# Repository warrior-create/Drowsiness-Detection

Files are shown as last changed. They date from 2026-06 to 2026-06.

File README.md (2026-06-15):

# 🚗 SafeDash — Real-Time Driver Drowsiness Detection & Monitoring System

> An embedded AI system for real-time driver attention monitoring, built on NVIDIA Jetson Nano.  
> Developed at the **School of Computing and Electrical Engineering, IIT Mandi**.

📄 [Project Report](https://drive.google.com/drive/folders/1U4jq64dsoF5--_NPGIv1SxsrH9lrvMU_) · 🎥 [Demo Videos](https://drive.google.com/drive/folders/1U4jq64dsoF5--_NPGIv1SxsrH9lrvMU_) · 🔩 [CAD Files](https://github.com/SHRI-14/SAFEDASH/tree/main/CAD)

---

## Overview

SafeDash is a low-cost, non-invasive driver monitoring system that detects drowsiness and inattention in real time using a standard USB webcam and the MediaPipe face tracking pipeline running on an NVIDIA Jetson Nano. When unsafe behaviour is detected, a three-stage alert mechanism (visual → audio → haptic) progressively re-engages the driver. All data is streamed to a Flask + Redis web dashboard for live and historical analysis.

---

## Features

- **Real-time facial landmark tracking** — MediaPipe Face Mesh extracts 468 landmarks per frame at 30+ FPS on-device
- **Unified Attention Score (1–5)** — computed from eye closure (EAR), yawning (MAR), blink rate, and head pose
- **Three-stage alert system**
  - 🖥️ Stage 1 — Visual warning on integrated LCD
  - 🔊 Stage 2 — Voice alert via external speaker
  - 📳 Stage 3 — Haptic feedback via steering-mounted vibration motors
- **Web dashboard** — live attention score, blink rate, head orientation (yaw/pitch/roll), eye state, and historical charts
- **Automatic email alerts** — SMTP notification to supervisors when attention drops below threshold (15-second cooldown)
- **Redis time-series storage** — data auto-expires after 24 hours; supports multi-device fleet monitoring
- **Face-not-detected logic** — triggers haptic + audio alert if face is absent for >4 seconds
- **Custom acrylic enclosure** — SolidWorks-designed, laser-cut black acrylic housing with thermal management

---

## System Architecture

```
USB Webcam
    │
    ▼
MediaPipe Face Mesh (468 landmarks)
    │
    ├── Eye Aspect Ratio (EAR)   →  Eye closure / blink detection
    ├── Mouth Aspect Ratio (MAR) →  Yawn detection
    ├── Blink Rate (BR)          →  Sliding 5s window
    └── Head Pose (Yaw/Pitch/Roll)
    │
    ▼
Unified Attention Score (1–5)
    │
    ├── Alert Engine  →  LCD / Speaker / Haptic Motors
    └── Flask Backend →  Redis →  Web Dashboard + Email Alerts
```

---

## Hardware

| Component | Details |
|---|---|
| Processor | NVIDIA Jetson Nano 4GB |
| Camera | USB Webcam (RGB, 30–45 FPS) |
| Display | 3.2-inch HDMI LCD |
| Audio | External speaker via USB sound card |
| Haptic | 2× DC vibration motors (steering-mounted) via L298N driver |
| Connectivity | Intel AC8265 Wi-Fi module |
| Storage | 32 GB micro-SD |
| Power | 12V (actuators) / 5V (Jetson & logic) via automotive buck converters |
| Enclosure | 3mm black acrylic, laser-cut, SolidWorks design |

**Total BOM cost: ~₹12,000**

---

## Software Stack

- **Edge (Jetson):** Python, MediaPipe, OpenCV, Haarcascade (fallback detector)
- **Backend:** Flask, Redis
- **Frontend:** Chart.js (real-time graphs), HTML/CSS dashboard
- **Alerts:** SMTP email

---

## Repository Structure

```
SAFEDASH/
├── model.py                          # Attention scoring & drowsiness detection logic
├── stream_server.py                  # Flask backend + Redis + dashboard server
├── haarcascade_eye.py                # Haarcascade eye detector (fallback)
├── haarcascade_frontalface_default.py # Haarcascade face detector (fallback)
├── test_driver.py                    # Testing / simulation script
└── CAD/                              # SolidWorks enclosure design files
```

---

## Getting Started

### Prerequisites

- NVIDIA Jetson Nano with JetPack installed (or any Linux machine for testing)
- Python 3.8+
- Redis server
- USB webcam

### Installation

```bash
# Clone the repository
git clone https://github.com/SHRI-14/SAFEDASH.git
cd SAFEDASH

# Create and activate virtual environment
python3 -m venv venv
source venv/bin/activate

# Install dependencies
pip install flask mediapipe opencv-python redis numpy
```

### Running

```bash
# Start Redis (in a separate terminal)
redis-server

# Start the stream server / dashboard
python3 stream_server.py
```

The dashboard will be available at **http://localhost:5001**

To run the drowsiness detection model on the Jetson:

```bash
python3 model.py
```

---

## Attention Scoring Algorithm

The system computes a normalized attention rating on a **1–5 scale**:

| Feature | Weight | Condition |
|---|---|---|
| Eye state (EAR) | 4 | Open = 1, Closed = 0 (threshold: EAR < 0.26) |
| Mouth state (MAR) | 2 | Closed = 1, Yawning = 0 (threshold: MAR > 0.40) |
| Head/Neck pose | 3 | 0–2 based on yaw/roll angles |
| Blink rate | 3 | Normal (1–3 blinks/s) = 1, else 0 |

**Raw score max = 15 → Normalized to 1–5 range**

Alert threshold: Score < 2

---

## Dashboard

The web dashboard supports:
- Live attention score with color-coded risk severity
- Real-time charts: attention score, blink frequency, head orientation (yaw/pitch/roll)
- Aggregated bar charts (1–60 min time ranges)
- Multi-device fleet monitoring via unique Jetson IDs
- Data refresh every 5 seconds

---

**School of Computing and Electrical Engineering, IIT Mandi**

**Advisors:** Dr. Rohit Saluja, Dr. Gajendra Singh

---

## Acknowledgements

Thanks to the School of Computing and Electrical Engineering at IIT Mandi for providing laboratory facilities, equipment, and technical guidance throughout the project.

---

## License

This project was developed for academic purposes at IIT Mandi. Please contact the authors for usage permissions.

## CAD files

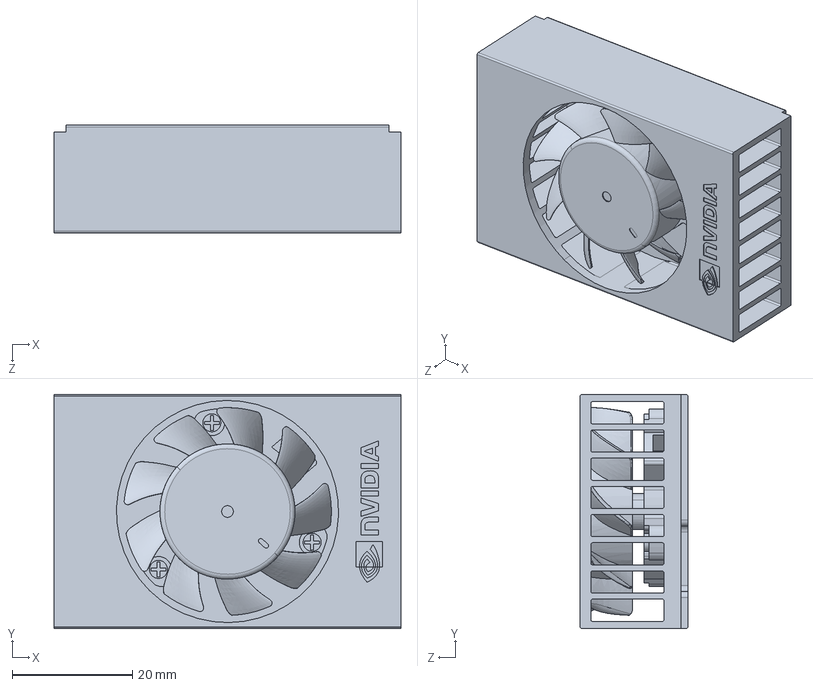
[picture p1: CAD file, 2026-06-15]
CAD/Xavier_NX_FANSINK_P3518_ASM[1].SLDPRT
57.8 x 39.0 x 18.0 mm

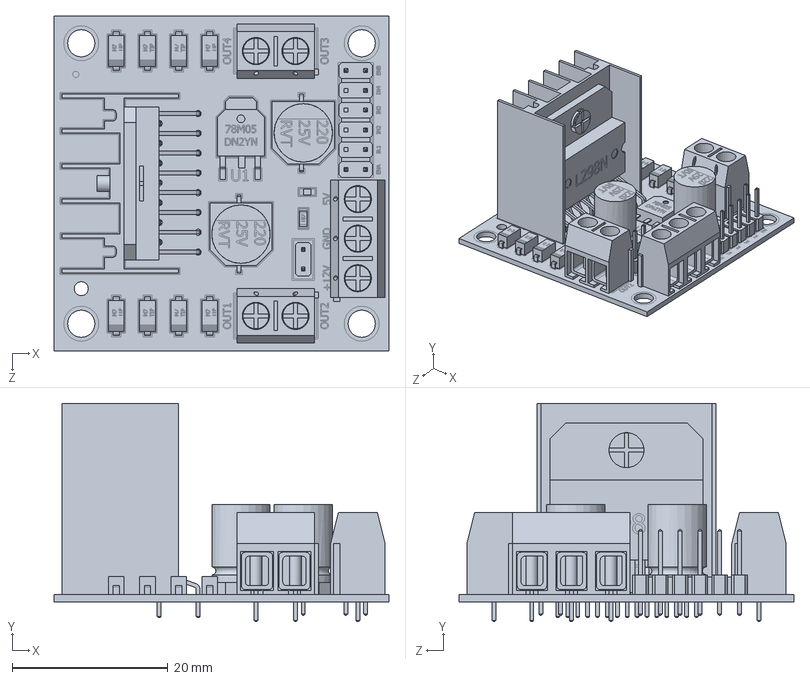
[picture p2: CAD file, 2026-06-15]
CAD/L298N.SLDPRT
43.0 x 28.0 x 43.0 mm

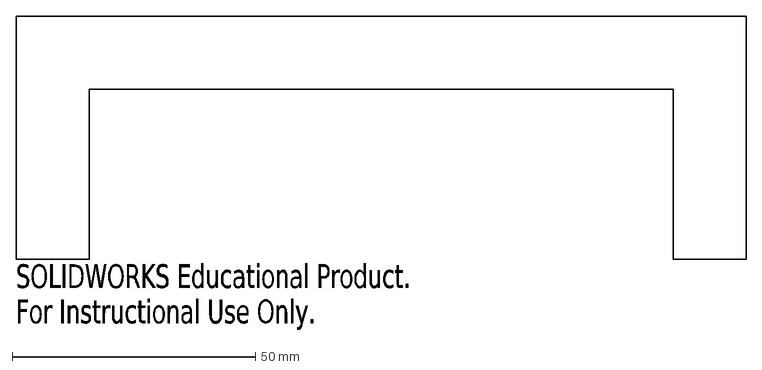
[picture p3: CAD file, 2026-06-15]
CAD/back.DXF
SOLIDWORKS Educational Product.
For Instructional Use Only.

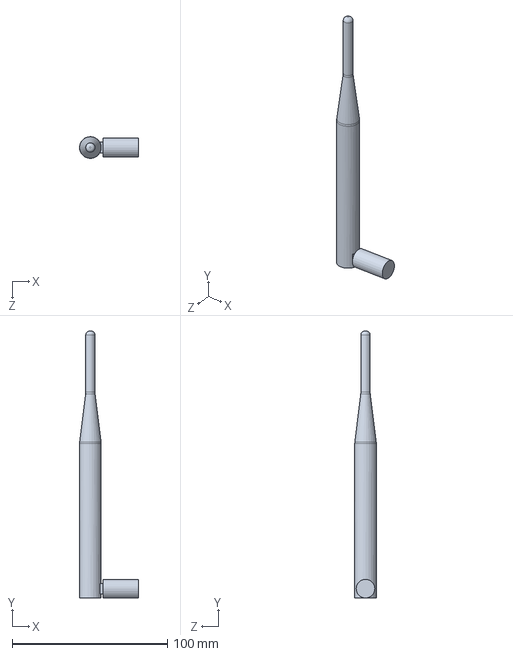
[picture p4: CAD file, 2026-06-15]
CAD/Antenna90deg[1].SLDPRT
38.0 x 172.0 x 14.0 mm

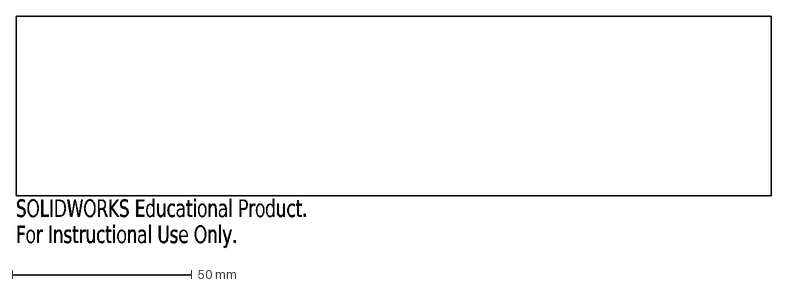
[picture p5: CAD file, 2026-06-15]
CAD/side.DXF
SOLIDWORKS Educational Product.
For Instructional Use Only.

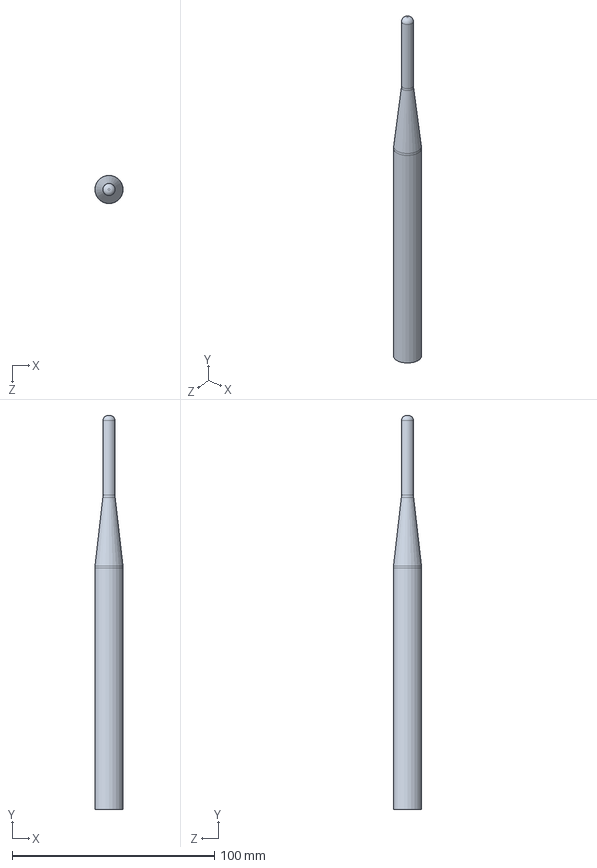
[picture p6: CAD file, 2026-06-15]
CAD/Antenna[1].SLDPRT
14.0 x 195.0 x 14.0 mm

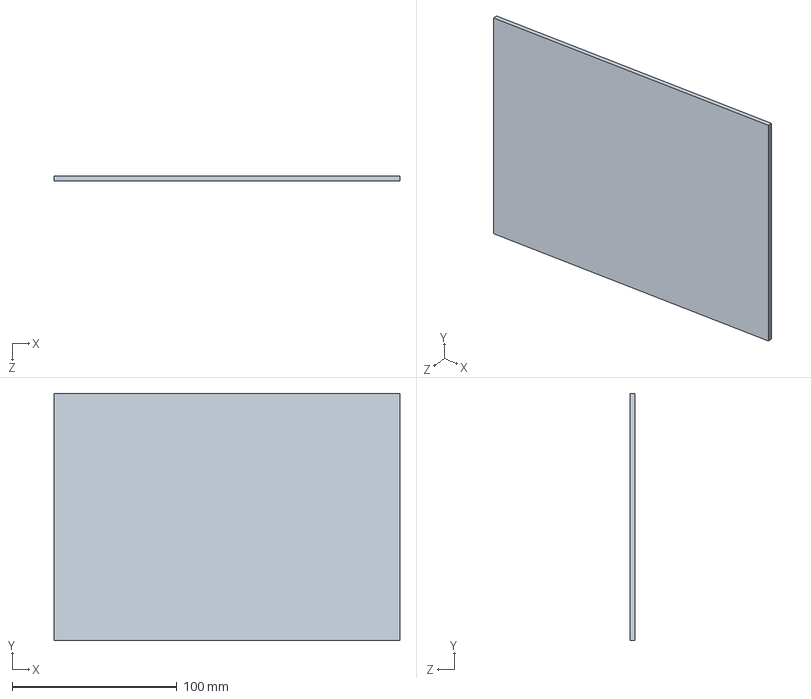
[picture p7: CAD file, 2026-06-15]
CAD/Part209.SLDPRT
210.0 x 150.0 x 3.00 mm

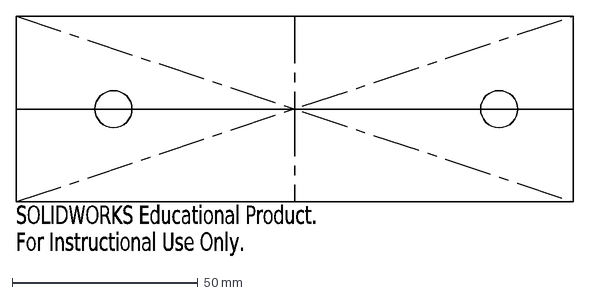
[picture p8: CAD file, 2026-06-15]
CAD/front.DXF
SOLIDWORKS Educational Product.
For Instructional Use Only.

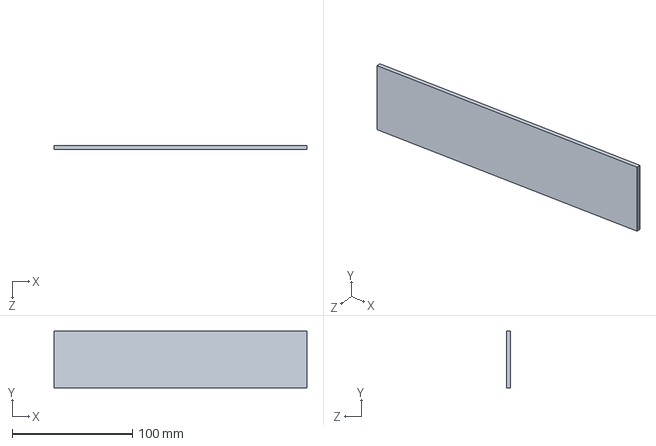
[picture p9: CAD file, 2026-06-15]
CAD/Part210.SLDPRT
210.0 x 47.0 x 3.00 mm

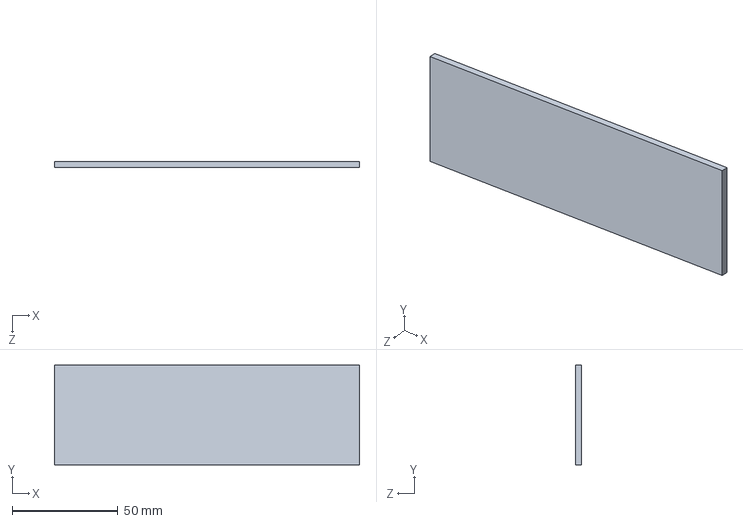
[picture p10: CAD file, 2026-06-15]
CAD/Part1.SLDPRT
144.0 x 47.0 x 3.00 mm

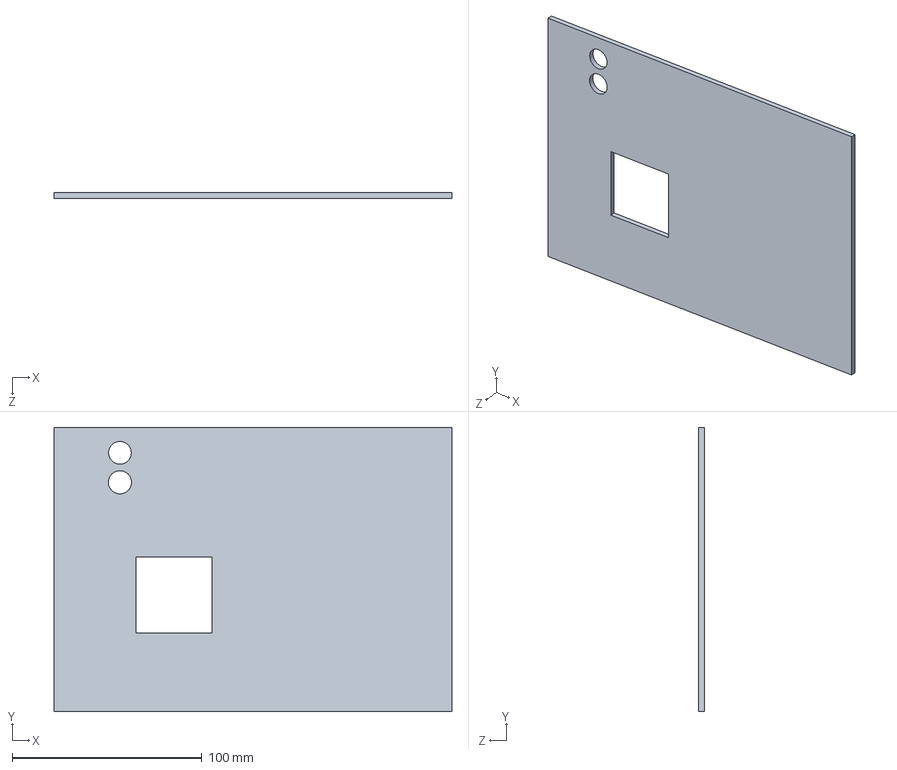
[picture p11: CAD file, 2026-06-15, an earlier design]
CAD/Part209 - Copy.SLDPRT
210.0 x 150.0 x 3.00 mm

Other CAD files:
CAD/top.SLDPRT
CAD/top2.SLDPRT
CAD/Part1 - Copy.SLDPRT
CAD/top.DXF
CAD/top.SLDDRW
CAD/top2.DXF

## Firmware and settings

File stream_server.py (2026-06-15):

from flask import Flask, request, jsonify, render_template_string
import redis
import json
from datetime import datetime, timedelta
import smtplib
from email.mime.text import MIMEText
from email.mime.multipart import MIMEMultipart
from threading import Thread, Lock
import time
from collections import Counter

app = Flask(__name__)

REDIS_HOST = 'localhost'
REDIS_PORT = 6379
REDIS_DB = 0
DATA_RETENTION_HOURS = 24

SMTP_SERVER = "smtp.gmail.com"
SMTP_PORT = 587

SENDER_EMAIL = "b24225@students.iitmandi.ac.in"
SENDER_PASSWORD = "vamcwrsjpsfjlzhq"
RECIPIENT_EMAIL = "b24160@students.iitmandi.ac.in"

ALERT_THRESHOLD = 2
ALERT_COOLDOWN = 15

redis_client = redis.Redis(
    host=REDIS_HOST,

    port=REDIS_PORT,
    db=REDIS_DB,
    decode_responses=True
)

alert_state = {}
alert_lock = Lock()

def store_data_in_redis(data):
    try:
        jetson_id = data.get('jetson_id', 'unknown')
        epoch_time = data.get('epoch_time', time.time())
        key = f"data:{jetson_id}:{epoch_time}"
        redis_client.setex(key, timedelta(hours=DATA_RETENTION_HOURS), json.dumps(data))
        redis_client.zadd(f"timeline:{jetson_id}", {key: epoch_time})
        redis_client.expire(f"timeline:{jetson_id}", timedelta(hours=DATA_RETENTION_HOURS))
        return True
    except Exception as e:
        print(f"Redis storage error: {e}")
        return False

def get_recent_data(jetson_id, hours=1):
    try:
        current_time = time.time()
        start_time = current_time - (hours * 3600)
        keys = redis_client.zrangebyscore(f"timeline:{jetson_id}", start_time, current_time)
        data_list = []
        for key in keys:
            data_str = redis_client.get(key)
            if data_str:
                data_list.append(json.loads(data_str))
        data_list.sort(key=lambda x: x.get('epoch_time', 0))
        return data_list
    except Exception as e:
        print(f"Redis retrieval error: {e}")
        return []

def send_alert_email(jetson_id, attention_score, data):
    try:
        # --- 1. Extract Location Data ---
        lat = data.get('latitude', 'N/A')
        lon = data.get('longitude', 'N/A')

        # --- 2. Generate Maps Link ---
        maps_section = ""
        if lat != 'N/A' and lon != 'N/A':
            maps_link = f"https://www.google.com/maps?q={lat},{lon}"
            maps_section = f"""
            <div style="margin-top: 20px; border-top: 1px solid #eee; padding-top: 15px;">
                <a href="{maps_link}" style="background-color: #1e40af; color: white; padding: 12px 20px; text-decoration: none; border-radius: 6px; font-weight: bold; display: inline-block;">
                    📍 View Location on Google Maps
                </a>
            </div>
            """

        subject = f"CRITICAL: Driver Attention Alert - {jetson_id}"
        
        # --- 3. Updated HTML Body ---
        body = f"""
        <html>
        <body style="font-family: 'Segoe UI', Arial, sans-serif; background-color: #f1f5f9; padding: 20px;">
            <div style="max-width: 600px; margin: 0 auto; background: white; border-radius: 12px; overflow: hidden; box-shadow: 0 4px 6px -1px rgba(0, 0, 0, 0.1);">
                
                <div style="background: #dc2626; color: white; padding: 24px; text-align: center;">
                    <h2 style="margin: 0; font-size: 24px; letter-spacing: 1px;">DRIVER SAFETY ALERT</h2>
                    <p style="margin: 5px 0 0 0; opacity: 0.9;">Immediate Attention Required</p>
                </div>

                <div style="padding: 30px;">
                    
                    <div style="text-align: center; margin-bottom: 25px; background: #fef2f2; padding: 15px; border-radius: 8px; border: 1px solid #fecaca;">
                        <p style="margin: 0; color: #7f1d1d; font-size: 14px; text-transform: uppercase; font-weight: bold;">Attention Score</p>
                        <div style="font-size: 36px; font-weight: 800; color: #dc2626; margin: 5px 0;">{attention_score}/5</div>
                        <div style="color: #991b1b; font-weight: 600;">{data.get('attention_label', 'N/A')}</div>
                    </div>

                    <table style="width: 100%; border-collapse: collapse; margin-bottom: 20px;">
                        <tr>
                            <td style="padding: 10px; border-bottom: 1px solid #e2e8f0; color: #64748b;">Vehicle ID</td>
                            <td style="padding: 10px; border-bottom: 1px solid #e2e8f0; font-weight: 600; color: #0f172a;">{jetson_id}</td>
                        </tr>
                        <tr>
                            <td style="padding: 10px; border-bottom: 1px solid #e2e8f0; color: #64748b;">Time</td>
                            <td style="padding: 10px; border-bottom: 1px solid #e2e8f0; font-weight: 600; color: #0f172a;">{data.get('timestamp', 'N/A')}</td>
                        </tr>
                        <tr>
                            <td style="padding: 10px; border-bottom: 1px solid #e2e8f0; color: #64748b;">Eye Status</td>
                            <td style="padding: 10px; border-bottom: 1px solid #e2e8f0; font-weight: 600; color: #0f172a;">{data.get('eye_status', 'N/A')}</td>
                        </tr>
                        <tr>
                            <td style="padding: 10px; border-bottom: 1px solid #e2e8f0; color: #64748b;">Drowsiness</td>
                            <td style="padding: 10px; border-bottom: 1px solid #e2e8f0; font-weight: 700; color: {'#dc2626' if data.get('is_drowsy', False) else '#16a34a'};">
                                {'DETECTED' if data.get('is_drowsy', False) else 'None'}
                            </td>
                        </tr>
                        <tr>
                            <td style="padding: 10px; border-bottom: 1px solid #e2e8f0; color: #64748b;">GPS Coordinates</td>
                            <td style="padding: 10px; border-bottom: 1px solid #e2e8f0; font-family: monospace; color: #0f172a;">
                                {lat}, {lon}
                            </td>
                        </tr>
                    </table>

                    {maps_section}

                </div>

                <div style="background: #f8fafc; padding: 15px; text-align: center; border-top: 1px solid #e2e8f0;">
                    <p style="margin: 0; font-size: 12px; color: #94a3b8;">
                        Sent automatically by Driver Safety Monitoring System<br>
                        Logged at: {datetime.now().strftime('%Y-%m-%d %H:%M:%S')}
                    </p>
                </div>
            </div>
        </body>
        </html>
        """
        
        msg = MIMEMultipart('alternative')
        msg['Subject'] = subject
        msg['From'] = SENDER_EMAIL
        msg['To'] = RECIPIENT_EMAIL
        html_part = MIMEText(body, 'html')
        msg.attach(html_part)
        
        server = smtplib.SMTP(SMTP_SERVER, SMTP_PORT)
        server.starttls()
        server.login(SENDER_EMAIL, SENDER_PASSWORD)
        server.send_message(msg)
        server.quit()
        return True
    except Exception as e:
        print(f"Email error: {e}")
        return False

def check_and_send_alert(data):
    jetson_id = data.get('jetson_id', 'unknown')
    attention_score = data.get('attention_score', 5)
    if attention_score < ALERT_THRESHOLD:
        with alert_lock:
            current_time = time.time()
            last_alert_time = alert_state.get(jetson_id, 0)
            if current_time - last_alert_time >= ALERT_COOLDOWN:
                Thread(target=send_alert_email, args=(jetson_id, attention_score, data), daemon=True).start()
                alert_state[jetson_id] = current_time

@app.route('/stream', methods=['POST'])
def receive_stream():
    try:
        data = request.get_json()
        if not data:
            return jsonify({"error": "No data received"}), 400
        if store_data_in_redis(data):
            check_and_send_alert(data)
            return jsonify({
                "status": "success",
                "message": "Data received and stored",
                "jetson_id": data.get('jetson_id'),
                "timestamp": data.get('timestamp')
            }), 200
        else:
            return jsonify({"error": "Failed to store data"}), 500
    except Exception as e:
        print(f"Error processing stream: {e}")
        return jsonify({"error": str(e)}), 500

@app.route('/api/data/<jetson_id>')
def get_data_api(jetson_id):
    hours = request.args.get('hours', default=1, type=int)
    data = get_recent_data(jetson_id, hours)
    return jsonify(data)

@app.route('/api/devices')
def get_devices():
    try:
        keys = redis_client.keys("timeline:*")
        devices = [key.replace("timeline:", "") for key in keys]
        return jsonify({"devices": devices})
    except Exception as e:
        return jsonify({"error": str(e)}), 500

@app.route('/')
def dashboard():
    return render_template_string(DASHBOARD_HTML)

@app.route('/dashboard/<jetson_id>')
def device_dashboard(jetson_id):
    return render_template_string(DEVICE_DASHBOARD_HTML, jetson_id=jetson_id)

DASHBOARD_HTML = '''
<!DOCTYPE html>
<html lang="en">
<head>
    <meta charset="UTF-8">
    <meta name="viewport" content="width=device-width, initial-scale=1.0">
    <title>Driver Safety Monitoring System</title>
    <script src="https://cdn.tailwindcss.com"></script>
    <script>
        tailwind.config = {
            theme: {
                extend: {
                    colors: {
                        primary: '#1e40af',
                        secondary: '#64748b',
                    }
                }
            }
        }
    </script>
</head>
<body class="bg-slate-50">
    <nav class="bg-white border-b border-slate-200">
        <div class="max-w-7xl mx-auto px-6 py-4">
            <div class="flex items-center justify-between">
                <div class="flex items-center space-x-4">
                    <div class="w-12 h-12 bg-blue-600 rounded-lg flex items-center justify-center">
                        <svg class="w-6 h-6 text-white" fill="none" stroke="currentColor" viewBox="0 0 24 24">
                            <path stroke-linecap="round" stroke-linejoin="round" stroke-width="2" d="M9 12l2 2 4-4m5.618-4.016A11.955 11.955 0 0112 2.944a11.955 11.955 0 01-8.618 3.04A12.02 12.02 0 003 9c0 5.591 3.824 10.29 9 11.622 5.176-1.332 9-6.03 9-11.622 0-1.042-.133-2.052-.382-3.016z"></path>
                        </svg>
                    </div>
                    <div>
                        <h1 class="text-xl font-bold text-slate-900">Driver Safety Monitor</h1>
                        <p class="text-sm text-slate-600">Real-time Fleet Management</p>
                    </div>
                </div>
                <div class="flex items-center space-x-2 px-4 py-2 bg-green-50 border border-green-200 rounded-lg">
                    <div class="w-2 h-2 bg-green-500 rounded-full animate-pulse"></div>
                    <span class="text-sm font-semibold text-green-700">System Active</span>
                </div>
            </div>
        </div>
    </nav>

    <main class="max-w-7xl mx-auto px-6 py-8">
        <div class="grid grid-cols-1 lg:grid-cols-3 gap-6 mb-8">
            <div class="bg-gradient-to-br from-blue-50 to-blue-100 rounded-xl p-6 border border-blue-200">
                <div class="w-16 h-16 bg-blue-600 rounded-xl flex items-center justify-center mb-4">
                    <svg class="w-10 h-10 text-white" fill="none" stroke="currentColor" viewBox="0 0 24 24">
                        <path stroke-linecap="round" stroke-linejoin="round" stroke-width="2" d="M15 12a3 3 0 11-6 0 3 3 0 016 0z"></path>
                        <path stroke-linecap="round" stroke-linejoin="round" stroke-width="2" d="M2.458 12C3.732 7.943 7.523 5 12 5c4.478 0 8.268 2.943 9.542 7-1.274 4.057-5.064 7-9.542 7-4.477 0-8.268-2.943-9.542-7z"></path>
                    </svg>
                </div>
                <h3 class="text-lg font-bold text-slate-900 mb-2">Eye Tracking</h3>
                <p class="text-sm text-slate-700">Real-time monitoring of eye movements, blink patterns, and gaze direction to detect driver attention levels</p>
            </div>

            <div class="bg-gradient-to-br from-purple-50 to-purple-100 rounded-xl p-6 border border-purple-200">
                <div class="w-16 h-16 bg-purple-600 rounded-xl flex items-center justify-center mb-4">
                    <svg class="w-10 h-10 text-white" fill="none" stroke="currentColor" viewBox="0 0 24 24">
                        <path stroke-linecap="round" stroke-linejoin="round" stroke-width="2" d="M12 8v4l3 3m6-3a9 9 0 11-18 0 9 9 0 0118 0z"></path>
                    </svg>
                </div>
                <h3 class="text-lg font-bold text-slate-900 mb-2">Drowsiness Detection</h3>
                <p class="text-sm text-slate-700">Advanced algorithms analyze facial features and behavior patterns to identify signs of driver fatigue</p>
            </div>

            <div class="bg-gradient-to-br from-green-50 to-green-100 rounded-xl p-6 border border-green-200">
                <div class="w-16 h-16 bg-green-600 rounded-xl flex items-center justify-center mb-4">
                    <svg class="w-10 h-10 text-white" fill="none" stroke="currentColor" viewBox="0 0 24 24">
                        <path stroke-linecap="round" stroke-linejoin="round" stroke-width="2" d="M9 12l2 2 4-4m6 2a9 9 0 11-18 0 9 9 0 0118 0z"></path>
                    </svg>
                </div>
                <h3 class="text-lg font-bold text-slate-900 mb-2">Head Pose Analysis</h3>
                <p class="text-sm text-slate-700">Track head orientation and position to ensure drivers maintain proper focus on the road ahead</p>
            </div>
        </div>

        <div class="mb-8">
            <h2 class="text-2xl font-bold text-slate-900 mb-2">Active Vehicle Fleet</h2>
            <p class="text-slate-600">Monitor driver attention and safety metrics in real-time</p>
        </div>

        <div id="vehicles" class="grid grid-cols-1 md:grid-cols-2 lg:grid-cols-3 gap-6">
            <div class="col-span-full flex justify-center items-center py-12">
                <div class="text-center">
                    <div class="w-12 h-12 border-4 border-slate-300 border-t-blue-600 rounded-full animate-spin mx-auto mb-4"></div>
                    <p class="text-slate-600">Loading vehicle data...</p>
                </div>
            </div>
        </div>
    </main>

    <script>
        function loadDevices() {
            fetch('/api/devices')
                .then(response => response.json())
                .then(data => {
                    const container = document.getElementById('vehicles');
                    if (data.devices.length === 0) {
                        container.innerHTML = '<div class="col-span-full text-center py-12"><p class="text-slate-600">No vehicles currently active</p></div>';
                        return;
                    }
                    container.innerHTML = '';
                    data.devices.forEach(device => {
                        const card = document.createElement('div');
                        card.className = 'bg-white rounded-xl border border-slate-200 p-6 hover:shadow-lg transition-all cursor-pointer hover:border-blue-500';
                        card.onclick = () => window.location.href = `/dashboard/${device}`;
                        card.innerHTML = `
                            <div class="flex items-start justify-between mb-4">
                                <div class="w-14 h-14 bg-gradient-to-br from-blue-500 to-blue-600 rounded-lg flex items-center justify-center">
                                    <svg class="w-7 h-7 text-white" fill="none" stroke="currentColor" viewBox="0 0 24 24">
                                        <path stroke-linecap="round" stroke-linejoin="round" stroke-width="2" d="M13 10V3L4 14h7v7l9-11h-7z"></path>
                                    </svg>
                                </div>
                                <span class="inline-flex items-center px-3 py-1 rounded-full text-xs font-medium bg-green-100 text-green-800">Active</span>
                            </div>
                            <h3 class="text-lg font-bold text-slate-900 mb-2">${device}</h3>
                            <div class="space-y-2 pt-4 border-t border-slate-100">
                                <div class="flex justify-between text-sm">
                                    <span class="text-slate-600">Status</span>
                                    <span class="font-medium text-slate-900">Monitoring</span>
                                </div>
                                <div class="flex justify-between text-sm">
                                    <span class="text-slate-600">Last Update</span>
                                    <span class="font-medium text-slate-900">Live</span>
                                </div>
                            </div>
                        `;
                        container.appendChild(card);
                    });
                })
                .catch(error => {
                    console.error('Error loading devices:', error);
                    document.getElementById('vehicles').innerHTML = '<div class="col-span-full text-center py-12"><p class="text-red-600">Error loading vehicle data</p></div>';
                });
        }
        loadDevices();
        setInterval(loadDevices, 5000);
    </script>
</body>
</html>
'''
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

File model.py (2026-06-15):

import cv2
import mediapipe as mp.   
import time
import numpy as np
import math
import subprocess
import tempfile
import os
import Jetson.GPIO as GPIO
from collections import deque
import json
import requests
from threading import Thread

# Initialize MediaPipe modules
mp_drawing = mp.solutions.drawing_utils
mp_face_mesh = mp.solutions.face_mesh

# ---- Face Mesh ----
face_mesh = mp_face_mesh.FaceMesh(
    static_image_mode=False,
    max_num_faces=1,
    min_detection_confidence=0.5,
    min_tracking_confidence=0.5
)

# ✅ NEW: Initialize Haar Cascade for eye detection
eye_cascade = cv2.CascadeClassifier(cv2.data.haarcascades + 'haarcascade_eye.xml')
face_cascade = cv2.CascadeClassifier(cv2.data.haarcascades + 'haarcascade_frontalface_default.xml')

# ---- Constants ----
EYE_CLOSURE_THRESH = 0.26
MOUTH_OPEN_THRESH = 0.40
DROWSY_TIME_THRESH = 3.5
FACE_NOT_DETECTED_VIBRATE_THRESH = 4.0

# ✅ NEW: Haar Cascade eye detection parameters
EYE_DETECTION_CONFIDENCE = 0.7  # Threshold for considering eyes as detected
CONSECUTIVE_FRAMES_FOR_BLINK = 2  # Frames with no eyes detected to register blink

# --- "ML Model" Weights ---
W_EYE_OPEN = 4
W_MOUTH = 2
W_NECK = 3
W_BLINK = 3
max_raw_score = (W_EYE_OPEN * 1) + (W_MOUTH * 1) + (W_NECK * 2) + (W_BLINK * 1)

# --- Blink Rate Constants ---
BLINK_TIME_WINDOW = 5.0
NORMAL_BLINK_MIN = 1
NORMAL_BLINK_MAX = 3

RATING_LABELS = {
    1:"Fully Distracted",
    2:"Distracted",
    3:"Bit Distracted",
    4:"Attentive",
    5:"Fully Attentive"
}

# ✅ NEW: Flask server configuration
JETSON_ID = "jetson-001"
FLASK_SERVER_URL = "http://YOUR_FLASK_SERVER_IP:5000/stream"  # Update this!
STREAM_INTERVAL = 5.0  # Send data every 5 seconds

neck_text_map = {3: "Straight", 2: "Slight Turn", 1: "Full Turn"}
blink_text_map = {1: "Strained", 2: "Staring", 3: "Normal"}

# ---- GPIO Pin Definitions ----
IN3_PIN = 38
IN4_PIN = 40
IN1_PIN = 35
IN2_PIN = 37

# ---- Helper Functions ----
def euclidean(a,b): return math.sqrt((a[0]-b[0])**2+(a[1]-b[1])**2)

def eye_aspect_ratio(landmarks, left=True):
    if left:
        ids = [33,160,158,133,153,144]
    else:
        ids = [263,387,385,362,380,373]
    pts = [(landmarks[i].x, landmarks[i].y) for i in ids]
    A = euclidean(pts[1], pts[5])
    B = euclidean(pts[2], pts[4])
    C = euclidean(pts[0], pts[3])
    return (A + B) / (2.0 * C)

# ✅ NEW: Haar Cascade-based eye detection for blink counting
def detect_eyes_haar(frame, face_roi=None):
    """
    Detect eyes using Haar Cascade classifier.
    Returns: (eyes_detected_count, eye_closed)
    """
    gray = cv2.cvtColor(frame, cv2.COLOR_BGR2GRAY)
    
    # If face ROI is provided, use it; otherwise detect face first
    if face_roi is not None:
        x, y, w, h = face_roi
        roi_gray = gray[y:y+h, x:x+w]
    else:
        faces = face_cascade.detectMultiScale(gray, 1.3, 5)
        if len(faces) == 0:
            return 0, True  # No face detected, assume eyes closed
        x, y, w, h = faces[0]
        roi_gray = gray[y:y+h, x:x+w]
    
    # Detect eyes in the face region
    eyes = eye_cascade.detectMultiScale(roi_gray, 1.1, 5, minSize=(20, 20))
    eyes_count = len(eyes)
    
    # If less than 2 eyes detected, consider eyes as closed
    eye_closed = eyes_count < 2
    
    return eyes_count, eye_closed

def mouth_open_ratio(landmarks):
    top, bottom = landmarks[13], landmarks[14]
    left, right = landmarks[78], landmarks[308]
    vertical = euclidean((top.x, top.y), (bottom.x, bottom.y))
    horizontal = euclidean((left.x, left.y), (right.x, right.y))
    return vertical / horizontal

def get_head_pose(landmarks):
    left_eye_3d = np.array([landmarks[33].x, landmarks[33].y, landmarks[33].z])
    right_eye_3d = np.array([landmarks[263].x, landmarks[263].y, landmarks[263].z])
    nose_3d = np.array([landmarks[1].x, landmarks[1].y, landmarks[1].z])
    face_vec = right_eye_3d - left_eye_3d
    
    yaw = np.degrees(np.arctan2(face_vec[2], face_vec[0])) * 2
    delta_y = landmarks[263].y - landmarks[33].y
    delta_x = landmarks[263].x - landmarks[33].x
    roll = np.degrees(np.arctan2(delta_y, delta_x))
    pitch = np.degrees((nose_3d[2] - (left_eye_3d[2] + right_eye_3d[2]) / 2) * 100)
    
    return yaw, pitch, roll

def say(text):
    try:
        tmp = tempfile.NamedTemporaryFile(suffix=".wav", delete=False)
        tmp_path = tmp.name
        tmp.close()
        subprocess.run(["pico2wave", "-w", tmp_path, text])
        command = f"paplay {tmp_path} && rm {tmp_path}"
        subprocess.Popen(command, shell=True, stdout=subprocess.DEVNULL, stderr=subprocess.DEVNULL)
    except Exception as e:
        print(f"TTS Error: {e}")
        if 'tmp_path' in locals() and os.path.exists(tmp_path):
            os.remove(tmp_path)

def motor_on():
    GPIO.output(IN3_PIN, GPIO.HIGH)
    GPIO.output(IN4_PIN, GPIO.LOW)
    time.sleep(0.25)
    GPIO.output(IN1_PIN, GPIO.HIGH)
    GPIO.output(IN2_PIN, GPIO.LOW)
    print("Motors ON")

def motor_off():
    GPIO.output(IN3_PIN, GPIO.LOW)
    GPIO.output(IN4_PIN, GPIO.LOW)
    GPIO.output(IN1_PIN, GPIO.LOW)
    GPIO.output(IN2_PIN, GPIO.LOW)
    print("Motors OFF")

# ✅ NEW: Function to send data to Flask server
def send_to_flask(data):
    """Send JSON data to Flask server in a separate thread"""
    def _send():
        try:
            response = requests.post(
                FLASK_SERVER_URL,
                json=data,
                timeout=3
            )
            if response.status_code == 200:
                print(f"✓ Data sent successfully at {data['timestamp']}")
            else:
                print(f"✗ Server returned status {response.status_code}")
        except requests.exceptions.RequestException as e:
            print(f"✗ Failed to send data: {e}")
    
    # Run in separate thread to avoid blocking
    Thread(target=_send, daemon=True).start()

# ---- Video Input ----
cap = cv2.VideoCapture(0, cv2.CAP_V4L2)
cap.set(cv2.CAP_PROP_FPS, 60)
cap.set(cv2.CAP_PROP_BUFFERSIZE, 1)

if not cap.isOpened():
    print("Error: Could not open video stream from USB camera.")
    exit()

fps = 30.0
print("Processing video from USB Cam | FPS:", fps)

blink_counter = 0
eye_was_open = True
eye_closed_start_time = 0

# ✅ NEW: Variables for Haar Cascade blink detection
eyes_closed_frames = 0  # Counter for consecutive frames with eyes closed
last_eye_state = "open"  # Track previous eye state

rating_buffer = deque(maxlen=2)
blink_timestamps = deque()

frame_width = int(cap.get(cv2.CAP_PROP_FRAME_WIDTH))
frame_height = int(cap.get(cv2.CAP_PROP_FRAME_HEIGHT))
print(f"Camera resolution: {frame_width} x {frame_height}")
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
